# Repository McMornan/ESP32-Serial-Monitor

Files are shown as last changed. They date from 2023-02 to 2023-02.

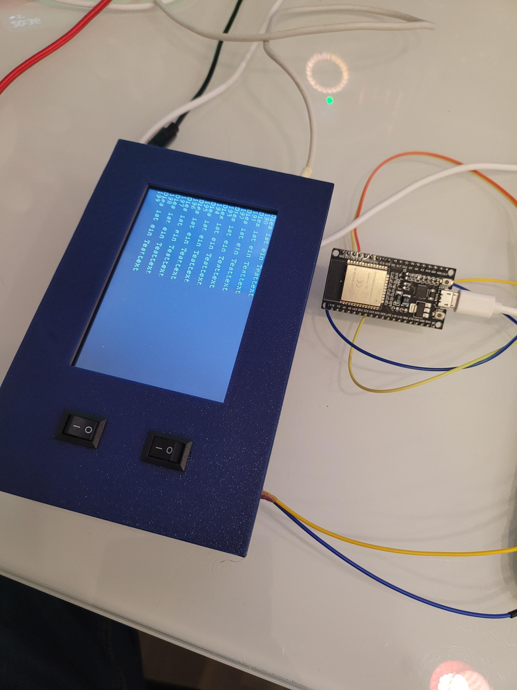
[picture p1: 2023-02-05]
20230205_203640.jpg

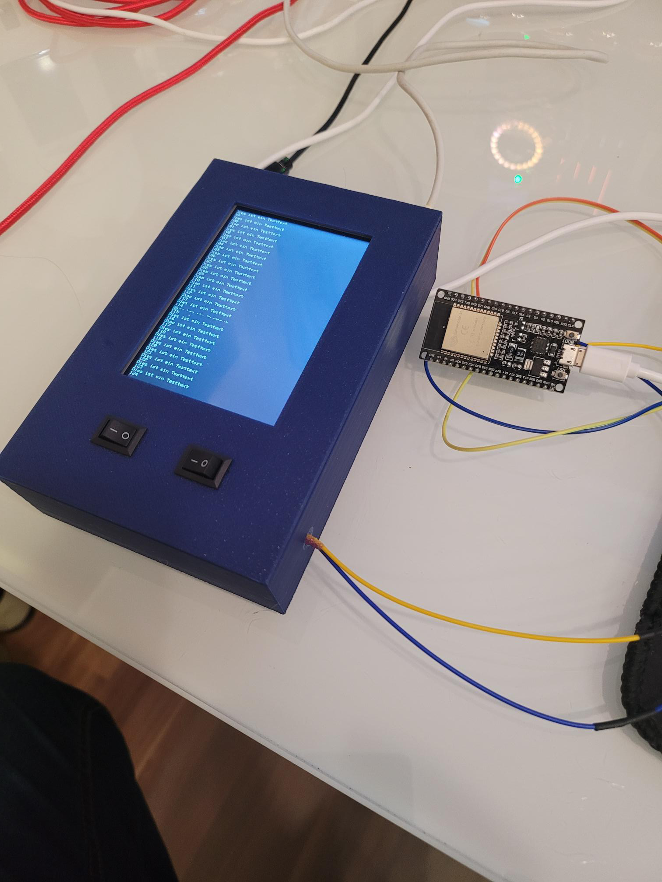
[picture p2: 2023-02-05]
20230205_203603.jpg

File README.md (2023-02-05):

# ESP32-Serial-Monitor

simple ESP32 monitor using a tft touch screen

Since the beginning of my maker career I struggled with the nonexistent debugging and remote monitoring capabilities of some chips like the standard arduino.
This device may help you in seeing those serial messages which of course only occur when your circuit is not connected to your computer :)

- tft screen with live config of font, orientation and baud rate
- pause switch for pausing the output
- telnet server to remotely monitor serial output (port 24 on ip address given to the esp32)

important:
- create the secrets file with write_data sketch (see my other repositories) first
- make sure to follow pin mapping when assembling

check out more details in the source code

BOM:
- an esp32 dev board
- a tft lcd screen which is supported by tft_espi library (ili9341, ST7789 etc.)
- lion charging circuit
- step up module to 5v (voltage might be unstable otherwise in battery mode)
- lion battery
- two switches (on/off) one for power on/off the other to toggle pause mode
- a 220uf, 10v cpacitator, close to 5v and ground on the esp32 board to buffer peaks during wlan transmission
- wires
- the 3d printed case - files are in the source directory

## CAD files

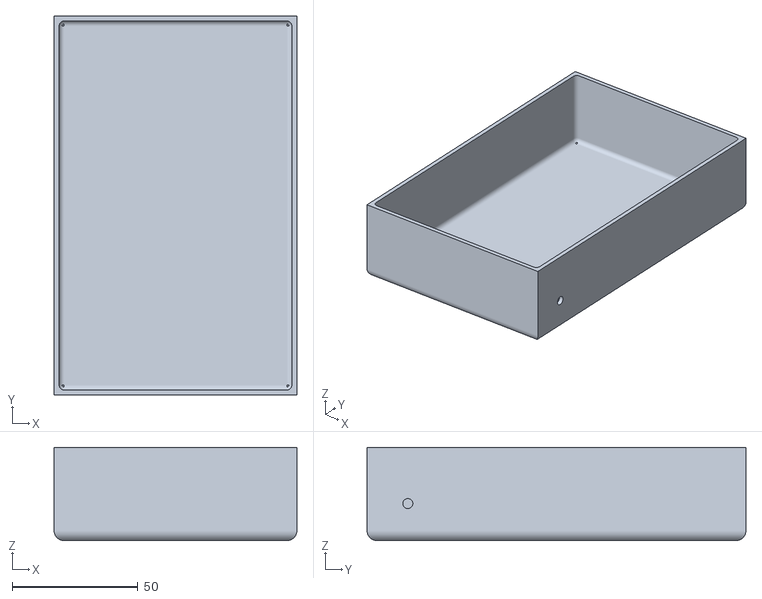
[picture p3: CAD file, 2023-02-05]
3dfiles/SerialMonitorCase.stl
96.4 x 150.4 x 37.0

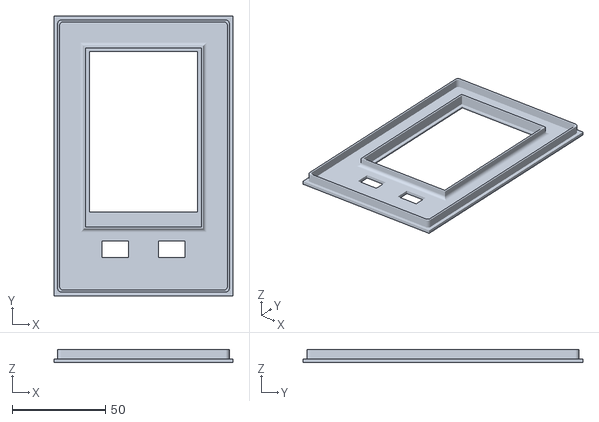
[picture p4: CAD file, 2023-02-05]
3dfiles/SerialMonitorCaseFront.stl
96.0 x 150.0 x 7.00

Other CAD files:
3dfiles/SerialMonitorCase.skp

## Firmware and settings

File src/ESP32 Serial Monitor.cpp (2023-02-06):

/**
 * @file ESP32 Serial Monitor.cpp
 * 
 * 
 * @author Lars Deutsch (deutsch.lars@gmail.com)
 * @brief this program implements a serial logger using the serial2 port of the esp32. screen orientation, font size and port speed can be configured during operation. Also the program implements a telnet server, which lets you monitor serial lines and debug information remotely
 * (My personal version comes with an usb-c charger for a 26650 li-ion battery - but feel free to power the circuit directly via usb-c or micro usb adapter)
 * The second swithc using pin 21 is used to halt serial output on the fly - when action is too fast to read ... attention: all messages received when in pause mode will be discarded !
 * 
 * To make this sketch work, you need to wire the data lines of a standard tft lcd display (mine uses 480x320, 4") according to the User_Setup.h file in the tft_espi library folder of the platform io project:
 * 
 * #define TOUCH_CS 4     // Chip select pin (T_CS) of touch screen
 * #define TFT_MISO 19
 * #define TFT_MOSI 23
 * #define TFT_SCLK 18
 * #define TFT_CS   5  // Chip select for TFT
 * #define TFT_DC   33  // Data Command control pin
 * #define TFT_RST  32  
 * #define TFT_BL   22  // LED back-light (required for M5Stack)
 * 
 * serial2 lines are pins 16 and 17
 * 
 * The sketch implements ArduinoOTA, port 8266, default pwd: 123
 * 
 * make sure to write the /secrets file to your esp32 flash memory before startup - see my other project on github https://github.com/McMornan
 * 
 * a custom case for your 3d printer can be found in the sourcecode
 * 
 * on my bucket list for improvements:
 * - implement WifiManager
 * - write log to sd card of tft screen (will need a new 3d printed case for this ...)
 * - level shifter 5v<->3,3v
 * - use two serial ports (would be a major overhaul, maybe with two tft displays)
 * - implement progress screen for OTA
 * - some minor glitches in scrollcode need fixing
 *  * 
 * @version 0.1
 * @date 2023-02-05
 * 
 * @copyright Copyright (c) 2023, MIT open source license
 * 
 */


#define DISPLAY_ON (HIGH)
#define DISPLAY_OFF (LOW)

#include "FS.h" // for touchscreen calibration data
#include "SPIFFS.h"
#define CALIBRATION_FILE "/TouchCalData2"
#define REPEAT_CAL false
#define STORAGE_FILE "/secrets"

#include <SPI.h>

#define USE_DMA_TO_TFT
#include "TFT_eSPI.h"
#include "Free_Fonts.h"
#include <ArduinoJson.h>
#include <WiFi.h>
#include <PubSubClient.h>
#include <WiFiUdp.h>
#include <ArduinoOTA.h>
#include <TelnetSpy.h>
#include <Wire.h>

#if not defined(ST7796_DRIVER) // check if tft_espi is configured correctly - change in header files and here for the display of your choice
  #error "wrong display driver defined!"
#endif


/**************************** FOR OTA **************************************************/
#define SENSORNAME "SerialMonitor" //change this to whatever you want to call your device
#define OTApassword "123" //the password you will need to enter to upload remotely via the ArduinoIDE
int OTAport = 8266;

/****************************************FOR JSON***************************************/
#define MQTT_MAX_PACKET_SIZE 1024

char strSecrets[5][20];
/************ WIFI and MQTT Information (MUST BE WRITTEN TO FILESYSTEM BY WRITE DATA PROGRAM FIRST!) ******************/
char* ssid = (char *)&strSecrets[0]; 
char* password = (char *)&strSecrets[1];
char* mqtt_server = (char *)&strSecrets[2];
char* mqtt_username = (char *)&strSecrets[3];
char* mqtt_password = (char *)&strSecrets[4];
int mqtt_port = 1883;
TFT_eSPI tft = TFT_eSPI();

// Create 12 buttons for the configuration menu
char keyLabel[12][15] = {"1", "2", "3","landscape","portrait","exit","9600","19200","38400","57600","115200","230400"};
uint16_t keyColor[12] = {TFT_BLACK, TFT_BLACK, TFT_BLACK,TFT_BLUE, TFT_BLUE, TFT_RED,TFT_DARKGREY,TFT_DARKGREY,TFT_DARKGREY,TFT_DARKGREY,TFT_DARKGREY,TFT_DARKGREY};
// Invoke the TFT_eSPI button class and create all the button objects
TFT_eSPI_Button key[12];

WiFiClient espClient;
PubSubClient client(espClient);

bool ConnectionEstablished; // Flag for successfully handled telnet connection on port 24
TelnetSpy LOG;

int fontsize = 1;     //font choosen by configuration
int serialspeed = 1;  //1-5 represents the serial speed of the serial2 port

int TEXT_HEIGHT=16; // initial height of text to be printed and scrolled
#define BOT_FIXED_AREA 0 // Number of lines in bottom fixed area (lines counted from bottom of screen)
#define TOP_FIXED_AREA 0 // Number of lines in top fixed area (lines counted from top of screen)
int YMAX = 480; 
int XMAX = 320;

// The initial y coordinate of the top of the scrolling area
uint16_t yStart = TOP_FIXED_AREA;
// yArea must be a integral multiple of TEXT_HEIGHT
uint16_t yArea = YMAX - TOP_FIXED_AREA-BOT_FIXED_AREA;
// The initial y coordinate of the top of the bottom text line
uint16_t yPos = TOP_FIXED_AREA;
uint16_t fontOffset = 0;

// Keep track of the drawing x coordinate
uint16_t xPos = 0;

// touch calibration routine. Will be executed once if you havent done so, yet. Execute before putting the display into the 3d printed case!
void touch_calibrate()
{
  uint16_t calData[5];
  uint8_t calDataOK = 0;

  // check if file system exists
  if (!SPIFFS.begin()) {
    Serial.println("Formating file system");
    SPIFFS.format();
    SPIFFS.begin();
  }

  // check if calibration file exists and size is correct
  if (SPIFFS.exists(CALIBRATION_FILE)) {
    if (REPEAT_CAL)
    {
      // Delete if we want to re-calibrate
      SPIFFS.remove(CALIBRATION_FILE);
    }
    else
    {
      File f = SPIFFS.open(CALIBRATION_FILE, "r");
      if (f) {
        if (f.readBytes((char *)calData, 14) == 14)
          calDataOK = 1;
        f.close();
      }
    }
  }

  if (calDataOK && !REPEAT_CAL) {
    // calibration data valid
    tft.setTouch(calData);
  } else {
    // data not valid so recalibrate
    tft.fillScreen(TFT_BLACK);
    tft.setCursor(20, 0);
    tft.setTextFont(2);
    tft.setTextSize(1);
    tft.setTextColor(TFT_WHITE, TFT_BLACK);

    tft.println("Touch corners as indicated");

    tft.setTextFont(1);
    tft.println();

    if (REPEAT_CAL) {
      tft.setTextColor(TFT_RED, TFT_BLACK);
      tft.println("Set REPEAT_CAL to false to stop this running again!");
    }

    tft.calibrateTouch(calData, TFT_MAGENTA, TFT_BLACK, 15);

    tft.setTextColor(TFT_GREEN, TFT_BLACK);
    tft.println("Calibration complete!");

    // store data
    File f = SPIFFS.open(CALIBRATION_FILE, "w");
    if (f) {
      f.write((const unsigned char *)calData, 14);
      f.close();
    }
  }
}

/********************************** START SETUP WIFI*****************************************/
void setup_wifi() {

  tft.fillScreen(TFT_BLACK);
  tft.setTextColor(TFT_WHITE);
  tft.setFreeFont(FM12);
  tft.setCursor(20, 20);

  delay(10);
  // We start by connecting to a WiFi network
  LOG.println();
  LOG.print("Connecting to ");
  LOG.println(ssid);

  tft.println();
  tft.print("Connecting to ");
  tft.println(ssid);

  LOG.print("WIFI status = ");
  LOG.println(WiFi.getMode());
  WiFi.disconnect(true);
  delay(1000);
  LOG.print("WIFI status = ");

  WiFi.mode(WIFI_STA);
  delay(1000);
  WiFi.begin(ssid, password);

  int nCount = 0;

  while (WiFi.status() != WL_CONNECTED)
  {
    Serial.print(".");
    tft.print(".");

    nCount ++;

    if (nCount >= 10) ESP.restart();

    delay(1000);
  }

  LOG.println("");
  LOG.println("WiFi connected");
  LOG.println("IP address: ");
  LOG.println(WiFi.localIP());

  tft.println("");
  tft.println("WiFi connected");
  tft.println("IP address: ");
  tft.println(WiFi.localIP());
}

/********************************** MQTT callback*****************************************/
void callback(char* topic, byte* payload, unsigned int length) {
  //if you feel the need for something fancy, the system can be reconfigured on the fly by mqtt packets ...
}

String macToStr(const uint8_t* mac)
{
  String result;
  for (int i = 0; i < 6; ++i) {
    result += String(mac[i], 16);
  }
  return result;
}

/********************************** START RECONNECT*****************************************/
void reconnect() {

  if (WiFi.status() != WL_CONNECTED) return;

  int nCount = 0;

  // Loop 10 times and then reboot
  LOG.print("Attempting MQTT connection...");
  client.setServer(mqtt_server, mqtt_port);
  client.setCallback(callback);

  while (!client.connected()) {
    LOG.print(".");
    delay(5000);

    String ClientId = "SerialMonitor_";
    unsigned char mac[6];
    WiFi.macAddress(mac);
    ClientId += macToStr(mac);

    // Attempt to connect
    if (client.connect(ClientId.c_str())) {
      LOG.println("connected");
      //client.subscribe(your_topic);
    } else {
      LOG.print("failed, rc=");
      LOG.print(client.state());
      LOG.println(" trying again in 5 seconds");
      // Wait 5 seconds before retrying
      delay(5000);
    }

    nCount ++;
    if ( nCount > 10) ESP.restart();
  }
}

// hardware scrolling only works in portrait mode - a shame ...
void setupScrollArea(uint16_t TFA, uint16_t BFA) {
  tft.writecommand(0x33); // Vertical scroll definition
  tft.writedata(TFA >> 8);
  tft.writedata(TFA);
  tft.writedata((YMAX - TFA - BFA) >> 8);
  tft.writedata(YMAX - TFA - BFA);
  tft.writedata(BFA >> 8);
  tft.writedata(BFA);
}

void scrollAddress(uint16_t vsp) {
  tft.writecommand(0x37); // Vertical scrolling pointer
  tft.writedata(vsp>>8);
  tft.writedata(vsp);
}

void setup(void) {
  LOG.begin(230400); // use fastest serial speed - also initializes serial0 port with 230400
  Serial2.begin(9600); // start with 9600 baud


  if (!SPIFFS.begin()) {
    LOG.println("error opening file system. STOP.");
    while(1);
  }

  // read Secrets from local filesystem
  if (SPIFFS.exists(STORAGE_FILE)) {
      File f = SPIFFS.open(STORAGE_FILE, "r");
      if (f) {
        if (f.readBytes((char *)strSecrets, 100) != 100) {
          LOG.println("secrets file read error ! STOP."); 
          while(1);
        }
        else {
          LOG.println("secrets read successfully ...");
          
          LOG.print("SSID: ");
          LOG.println(strSecrets[0]);
          
          LOG.print("PASSWORD: ");
          LOG.println(strSecrets[1]);
          
          LOG.print("MQTT SERVER: ");
          LOG.println(strSecrets[2]);
          
          LOG.print("MQTT USERNAME: ");
          LOG.println(strSecrets[3]);
          
          LOG.print("MQTT PASSWORD: ");
          LOG.println(strSecrets[4]);
        }
        f.close();
      } else {
        LOG.println("error opening secrets file. STOP.");
        while(1);
      }
  }
  
  pinMode(TFT_BL, OUTPUT); // switch Display LED on
  digitalWrite(TFT_BL, DISPLAY_ON);

  pinMode(21, INPUT_PULLUP); // pause switch pin setup

  tft.init();
  tft.setRotation(0); //portrait orientation
  touch_calibrate();

  setup_wifi();
  client.setServer(mqtt_server, mqtt_port);
  client.setCallback(callback);
  //OTA SETUP
  ArduinoOTA.setPort(OTAport);
  // Hostname defaults to esp8266-[ChipID]
  ArduinoOTA.setHostname(SENSORNAME);

  // No authentication by default, so we set a password
  ArduinoOTA.setPassword((const char *)OTApassword);

  ArduinoOTA.onStart([]() {
    LOG.println("Starting");
  });
  ArduinoOTA.onEnd([]() {
    LOG.println("\nEnd");
  });
  ArduinoOTA.onProgress([](unsigned int progress, unsigned int total) {
  });
  ArduinoOTA.onError([](ota_error_t error) {
    LOG.printf("Error[%u]: ", error);
    if (error == OTA_AUTH_ERROR) {
      LOG.println("Auth Failed");
    }
    else if (error == OTA_BEGIN_ERROR) {
      LOG.println("Begin Failed");
    }
    else if (error == OTA_CONNECT_ERROR) {
      LOG.println("Connect Failed");
    }
    else if (error == OTA_RECEIVE_ERROR) {
      LOG.println("Receive Failed");
    }
    else if (error == OTA_END_ERROR) {
      LOG.println("End Failed");
    }
    delay(1000);
    ESP.restart();
  });
  ArduinoOTA.begin();

  LOG.setPort(24);
  LOG.setWelcomeMsg("Serial Logger\n\n");
  LOG.setDebugOutput(false);

  tft.fillScreen(TFT_BLACK);
  tft.setTextColor(TFT_WHITE);
  tft.setCursor(4,0);
  tft.setTextFont(1);
  TEXT_HEIGHT = tft.fontHeight(1)+1;
  tft.print("ready...9600 baud");

  setupScrollArea(TOP_FIXED_AREA, BOT_FIXED_AREA);

  if(digitalRead(21) == LOW) {
    tft.setFreeFont(FMB24);
    tft.setCursor(20,80);
    tft.setTextColor(TFT_RED);
    tft.print("ATTENTION: \nPAUSE \nTRIGGERED!");

    while(digitalRead(21) == LOW);

    tft.fillScreen(TFT_BLACK);
    tft.setCursor(20,80);
    tft.setTextColor(TFT_GREEN);
    tft.println("CONTINUE...");

    tft.setTextColor(TFT_WHITE);
    tft.setTextFont(1);  
    delay(1000);
    tft.fillScreen(TFT_BLACK);
  }
}

int configMenu(int orientation)
{
  tft.fillScreen(TFT_BLACK);
  tft.setRotation(1);
  scrollAddress(0); // reset scroll shift

  tft.setTextColor(TFT_WHITE);
  tft.setFreeFont(FM18);
  tft.setCursor(50,35);
  tft.println("fontsize");

  tft.setCursor(50,125);
  tft.println("screen orientation");

  tft.setCursor(50,205);
  tft.println("serial speed");

  tft.setFreeFont(FM12);
  key[0].initButton(&tft, 70, 70, 62,40, TFT_WHITE, keyColor[0], TFT_WHITE, keyLabel[0], 1);
  key[0].drawButton();

  key[1].initButton(&tft, 150, 70, 62,40, TFT_WHITE, keyColor[1], TFT_WHITE, keyLabel[1], 1);
  key[1].drawButton();

  key[2].initButton(&tft, 230, 70, 62,40, TFT_WHITE, keyColor[2], TFT_WHITE, keyLabel[2], 1);
  key[2].drawButton();

  key[3].initButton(&tft, 130, 155, 140,40, TFT_WHITE, keyColor[3], TFT_WHITE, keyLabel[3], 1);
  key[3].drawButton();

  key[4].initButton(&tft, 290, 155, 140,40, TFT_WHITE, keyColor[4], TFT_WHITE, keyLabel[4], 1);
  key[4].drawButton();

  key[5].initButton(&tft, 410, 290, 120,40, TFT_WHITE, keyColor[5], TFT_WHITE, keyLabel[5], 1);
  key[5].drawButton();

  tft.setFreeFont(FM9);
  key[6].initButton(&tft, 45, 235, 65,40, TFT_WHITE, keyColor[6], TFT_WHITE, keyLabel[6], 1);
  key[6].drawButton();

  key[7].initButton(&tft, 116, 235, 74,40, TFT_WHITE, keyColor[7], TFT_WHITE, keyLabel[7], 1);
  key[7].drawButton();

  key[8].initButton(&tft, 191, 235, 74,40, TFT_WHITE, keyColor[8], TFT_WHITE, keyLabel[8], 1);
  key[8].drawButton();

  key[9].initButton(&tft, 268, 235, 74,40, TFT_WHITE, keyColor[9], TFT_WHITE, keyLabel[9], 1);
  key[9].drawButton();

  key[10].initButton(&tft, 343, 235, 75,40, TFT_WHITE, keyColor[10], TFT_WHITE, keyLabel[10], 1);
  key[10].drawButton();

  key[11].initButton(&tft, 419, 235, 75,40, TFT_WHITE, keyColor[11], TFT_WHITE, keyLabel[11], 1);
  key[11].drawButton();

  uint16_t t_x = 0, t_y = 0; // To store the touch coordinates

  long timeout = millis();
  

  while((millis() - timeout) < 10000) {
    // Pressed will be set true is there is a valid touch on the screen
    bool pressed = tft.getTouch(&t_x, &t_y);

    // / Check if any key coordinate boxes contain the touch coordinates
    for (uint8_t b = 0; b < 12; b++) {
      if (pressed && key[b].contains(t_x, t_y)) {
        key[b].press(true);  // tell the button it is pressed
      } else {
        key[b].press(false);  // tell the button it is NOT pressed
      }
    }

    // Check if any key has changed state
    for (uint8_t b = 0; b < 12; b++) {
      if (key[b].justReleased()) key[b].drawButton();     // draw normal

      if (key[b].justPressed()) {
        key[b].drawButton(true);  // draw invert

        if (b < 3) {
          fontsize = b +1;
          return orientation;
        }
        if (b == 3) {
          orientation = 1; 
          return orientation;
        }
        if (b == 4) {
          orientation = 0;  
          return orientation;
        }
        if (b == 5) {
          return orientation;
        }
        if (b > 5) {
          serialspeed = b - 5;
          return orientation;
        }
        delay(10);
      }
    }
  }
return orientation;
}

int scroll_line() {
  int yTemp = yStart;

  if (tft.getRotation() == 1) {
    yStart += TEXT_HEIGHT;
    if (yStart >= (YMAX - BOT_FIXED_AREA)) {
      yStart = TOP_FIXED_AREA + fontOffset;
      tft.fillScreen(TFT_BLACK);
    }
    yTemp = yStart;
  } else {
    for (int i = 0; i < TEXT_HEIGHT; i++) {
      yStart++;
      if (yStart == (YMAX - BOT_FIXED_AREA)) {
        yStart = TOP_FIXED_AREA + fontOffset;
      }
      scrollAddress(yStart);
    }
    tft.fillRect(0,yTemp,XMAX,TEXT_HEIGHT, TFT_BLACK);
  }
  return yTemp;
}

void loop(void) {
  if (WiFi.status() != WL_CONNECTED) {
    delay(1);
    LOG.print("WIFI disconnected. Attempting reconnection.");
    setup_wifi();
    return;
  }

  if (!client.connected()) {
    reconnect();
  }

  client.loop();
  ArduinoOTA.handle();
  LOG.handle();

  uint16_t x,y;

  if( tft.getTouch(&x,&y)) {
    int orientation = tft.getRotation();
    int newOrientation = configMenu(orientation);
    tft.fillScreen(TFT_BLACK);
    tft.setTextColor(TFT_WHITE);
    tft.setCursor(4,fontOffset);

    switch(newOrientation) {
      case 0: // hardware scroll in portrait mode
        tft.setRotation(newOrientation);
        XMAX=320;
        YMAX=480;
        yStart = yPos = TOP_FIXED_AREA;
        setupScrollArea(TOP_FIXED_AREA, BOT_FIXED_AREA);
        break;

      case 1: // screen blanking in landscape mode
        tft.setRotation(newOrientation);
        XMAX=480;
        YMAX=320;
        yStart = yPos = TOP_FIXED_AREA;
        break;
    }
    switch(fontsize) {
      case 1: tft.setTextFont(1);TEXT_HEIGHT = tft.fontHeight(1)+1;fontOffset = 0;break;
      case 2: tft.setFreeFont(FM9);TEXT_HEIGHT = 15;fontOffset = 10;break;
      case 3: tft.setFreeFont(FM12);TEXT_HEIGHT = 18;fontOffset = 18;break;
      case 4: tft.setFreeFont(FM24);TEXT_HEIGHT = 30;fontOffset = 32;break;
    }
    
    int baudrate = 115200;

    switch(serialspeed) {
      case 1: baudrate = 9600;break;
      case 2: baudrate = 19200;break;
      case 3: baudrate = 38400;break;
      case 4: baudrate = 57600;break;
      case 5: baudrate = 115200;break;
      case 6: baudrate = 230400;break;
    }

    Serial2.end();
    Serial2.begin(baudrate);

    tft.print("ready...");
    tft.print(baudrate);
    tft.println(" baud");
    delay(500);
  }

  byte data = 0;

  while (Serial2.available()) {
    data = Serial2.read();

    if(digitalRead(21)) { // only show read data when pause switch has not been triggered
      // If it is a CR or we are near end of line then scroll one line
      if (data == '\r' || xPos>(XMAX - 10)) {
        xPos = 0;
        yPos = scroll_line(); 
        LOG.println();
      }
      if (data > 31 && data < 128) {
        xPos += tft.drawChar(data,xPos,yPos);

        char str[2];
        str[0] = data;
        str[1] = 0;
        LOG.print(str);
      }
    }
  }
}

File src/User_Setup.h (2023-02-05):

//                            USER DEFINED SETTINGS
//   Set driver type, fonts to be loaded, pins used and SPI control method etc
//
//   See the User_Setup_Select.h file if you wish to be able to define multiple
//   setups and then easily select which setup file is used by the compiler.
//
//   If this file is edited correctly then all the library example sketches should
//   run without the need to make any more changes for a particular hardware setup!
//   Note that some sketches are designed for a particular TFT pixel width/height


// ##################################################################################
//
// Section 1. Call up the right driver file and any options for it
//
// ##################################################################################

// Define STM32 to invoke optimised processor support (only for STM32)
//#define STM32

// Defining the STM32 board allows the library to optimise the performance
// for UNO compatible "MCUfriend" style shields
//#define NUCLEO_64_TFT
//#define NUCLEO_144_TFT

// STM32 8 bit parallel only:
// If STN32 Port A or B pins 0-7 are used for 8 bit parallel data bus bits 0-7
// then this will improve rendering performance by a factor of ~8x
//#define STM_PORTA_DATA_BUS
//#define STM_PORTA_DATA_BUS

// Tell the library to use 8 bit parallel mode (otherwise SPI is assumed)
//#define TFT_PARALLEL_8_BIT

// Display type -  only define if RPi display
//#define RPI_DISPLAY_TYPE // 20MHz maximum SPI

// Only define one driver, the other ones must be commented out
//#define ILI9341_DRIVER
//#define ST7735_DRIVER      // Define additional parameters below for this display
//#define ILI9163_DRIVER     // Define additional parameters below for this display
//#define S6D02A1_DRIVER
//#define RPI_ILI9486_DRIVER // 20MHz maximum SPI
//#define HX8357D_DRIVER
//#define ILI9481_DRIVER
//#define ILI9486_DRIVER
//#define ILI9488_DRIVER     // WARNING: Do not connect ILI9488 display SDO to MISO if other devices share the SPI bus (TFT SDO does NOT tristate when CS is high)
//#define ST7789_DRIVER      // Full configuration option, define additional parameters below for this display
//#define ST7789_2_DRIVER    // Minimal configuration option, define additional parameters below for this display
//#define R61581_DRIVER
//#define RM68140_DRIVER
#define ST7796_DRIVER
//#define SSD1963_480_DRIVER    // Untested
//#define SSD1963_800_DRIVER    // Untested
//#define SSD1963_800ALT_DRIVER // Untested

// Some displays support SPI reads via the MISO pin, other displays have a single
// bi-directional SDA pin and the library will try to read this via the MOSI line.
// To use the SDA line for reading data from the TFT uncomment the following line:

// #define TFT_SDA_READ      // This option is for ESP32 ONLY, tested with ST7789 display only

// For ST7789 and ILI9341 ONLY, define the colour order IF the blue and red are swapped on your display
// Try ONE option at a time to find the correct colour order for your display

//  #define TFT_RGB_ORDER TFT_RGB  // Colour order Red-Green-Blue
//  #define TFT_RGB_ORDER TFT_BGR  // Colour order Blue-Green-Red

// For M5Stack ESP32 module with integrated ILI9341 display ONLY, remove // in line below

// #define M5STACK

// For ST7789, ST7735 and ILI9163 ONLY, define the pixel width and height in portrait orientation
// #define TFT_WIDTH  80
// #define TFT_WIDTH  128
// #define TFT_WIDTH  240 // ST7789 240 x 240 and 240 x 320
// #define TFT_HEIGHT 160
// #define TFT_HEIGHT 128
// #define TFT_HEIGHT 240 // ST7789 240 x 240
// #define TFT_HEIGHT 320 // ST7789 240 x 320

// For ST7735 ONLY, define the type of display, originally this was based on the
// colour of the tab on the screen protector film but this is not always true, so try
// out the different options below if the screen does not display graphics correctly,
// e.g. colours wrong, mirror images, or tray pixels at the edges.
// Comment out ALL BUT ONE of these options for a ST7735 display driver, save this
// this User_Setup file, then rebuild and upload the sketch to the board again:

// #define ST7735_INITB
// #define ST7735_GREENTAB
// #define ST7735_GREENTAB2
// #define ST7735_GREENTAB3
// #define ST7735_GREENTAB128    // For 128 x 128 display
// #define ST7735_GREENTAB160x80 // For 160 x 80 display (BGR, inverted, 26 offset)
// #define ST7735_REDTAB
// #define ST7735_BLACKTAB
// #define ST7735_REDTAB160x80   // For 160 x 80 display with 24 pixel offset

// If colours are inverted (white shows as black) then uncomment one of the next
// 2 lines try both options, one of the options should correct the inversion.

// #define TFT_INVERSION_ON
// #define TFT_INVERSION_OFF


// ##################################################################################
//
// Section 2. Define the pins that are used to interface with the display here
//
// ##################################################################################

// If a backlight control signal is available then define the TFT_BL pin in Section 2
// below. The backlight will be turned ON when tft.begin() is called, but the library
// needs to know if the LEDs are ON with the pin HIGH or LOW. If the LEDs are to be
// driven with a PWM signal or turned OFF/ON then this must be handled by the user
// sketch. e.g. with digitalWrite(TFT_BL, LOW);

 #define TFT_BL   22            // LED back-light control pin
 #define TFT_BACKLIGHT_ON HIGH  // Level to turn ON back-light (HIGH or LOW)



// We must use hardware SPI, a minimum of 3 GPIO pins is needed.
// Typical setup for ESP8266 NodeMCU ESP-12 is :
//
// Display SDO/MISO  to NodeMCU pin D6 (or leave disconnected if not reading TFT)
// Display LED       to NodeMCU pin VIN (or 5V, see below)
// Display SCK       to NodeMCU pin D5
// Display SDI/MOSI  to NodeMCU pin D7
// Display DC (RS/AO)to NodeMCU pin D3
// Display RESET     to NodeMCU pin D4 (or RST, see below)
// Display CS        to NodeMCU pin D8 (or GND, see below)
// Display GND       to NodeMCU pin GND (0V)
// Display VCC       to NodeMCU 5V or 3.3V
//
// The TFT RESET pin can be connected to the NodeMCU RST pin or 3.3V to free up a control pin
//
// The DC (Data Command) pin may be labeled AO or RS (Register Select)
//
// With some displays such as the ILI9341 the TFT CS pin can be connected to GND if no more
// SPI devices (e.g. an SD Card) are connected, in this case comment out the #define TFT_CS
// line below so it is NOT defined. Other displays such at the ST7735 require the TFT CS pin
// to be toggled during setup, so in these cases the TFT_CS line must be defined and connected.
//
// The NodeMCU D0 pin can be used for RST
//
//
// Note: only some versions of the NodeMCU provide the USB 5V on the VIN pin
// If 5V is not available at a pin you can use 3.3V but backlight brightness
// will be lower.


// ###### EDIT THE PIN NUMBERS IN THE LINES FOLLOWING TO SUIT YOUR ESP8266 SETUP ######
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
